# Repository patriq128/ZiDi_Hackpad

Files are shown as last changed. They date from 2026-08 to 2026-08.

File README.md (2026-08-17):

# ZiDi_Hackpad

My Hackpad is a 6-key macropad with an OLED display, rotary encoder, and my own custom firmware.

## Features

* 6 keys in a matrix
* EC11 rotary encoder
* 128x32 OLED display
* Custom firmware

## CAD Model

I am not very experienced with CAD, but I gave it a try.

The case is held together with 4 M3 bolts and heat-set inserts. The PCB is not directly mounted to the case; instead, it is supported by external supports that keep it securely in position.

The case consists of two parts: a bottom and a top. I left a small gap between the parts to make sure they fit together properly.

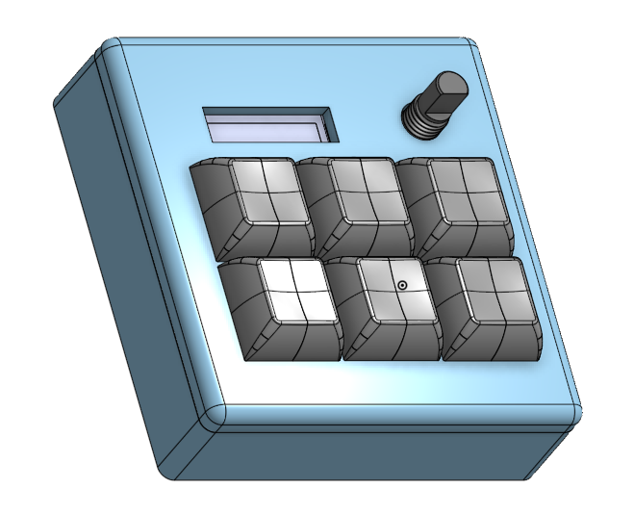
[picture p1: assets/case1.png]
case1


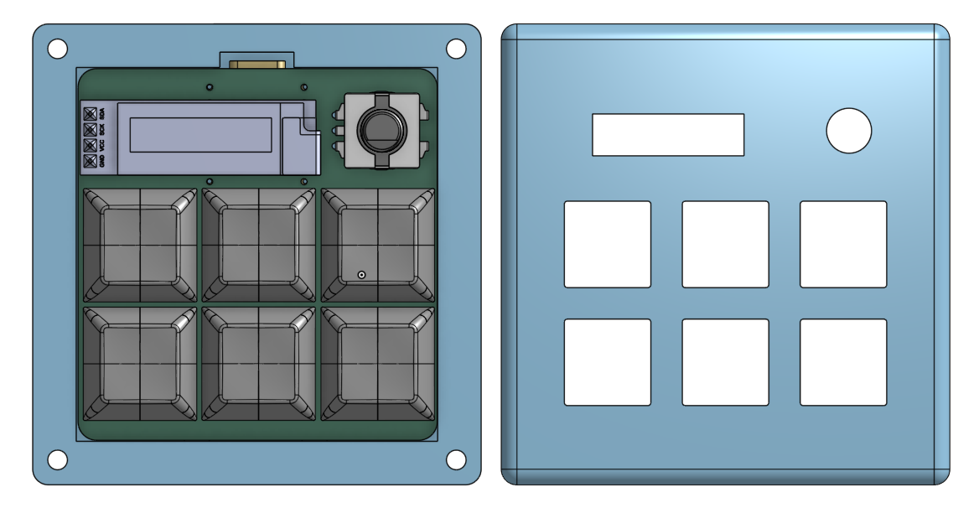
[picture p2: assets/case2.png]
case2


Made in **Onshape**.

## PCB

The PCB was designed in **KiCad**.

### Schematic

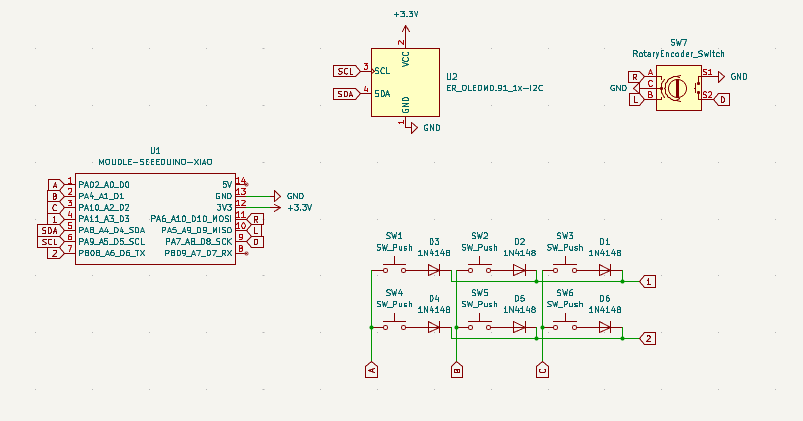
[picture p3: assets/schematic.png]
schematic


The schematic is quite basic, but it works.

### PCB

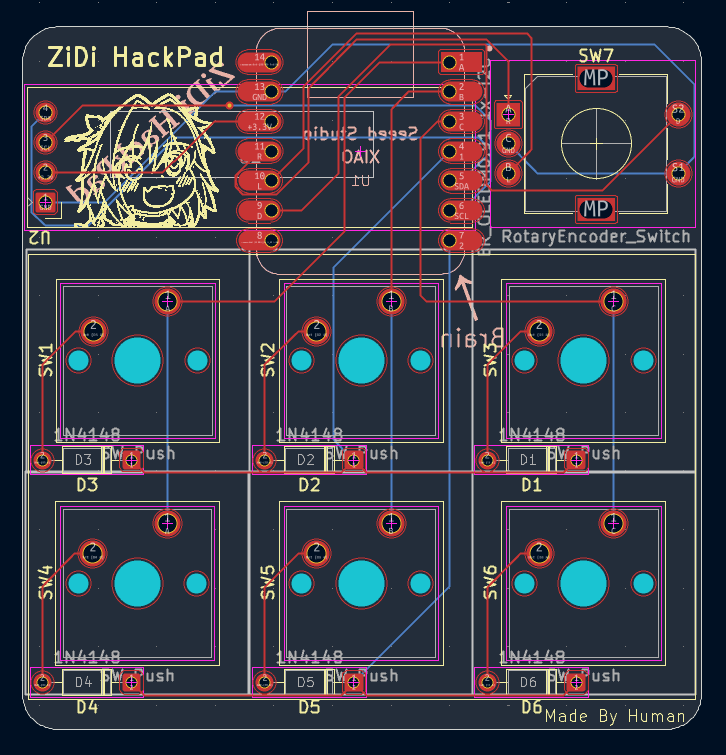
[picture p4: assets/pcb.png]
pcb




## Firmware

I decided to make the firmware a separate project, so you can find it here:



The `Firmware` folder contains everything you need to run the firmware, including a `conf.json` file with some example modes.

The `production` folder contains `firmware.uf2`, which is the CircuitPython firmware compiled and packaged as a UF2 file, ready to be flashed onto the device.

> Want to create something similar yourself? Check out this guide: [Create Custom UF2 File for Easy CircuitPython Flashing](https://embeddedcomputing.com/technology/open-source/create-custom-uf2-file-for-easy-circuitpython-flashing)

## BOM

* 6x Cherry MX switches
* 6x DSA keycaps
* 6x 1N4148 DO-35 diodes
* 1x 0.91" 128x32 OLED display
* 1x EC11 rotary encoder
* 1x XIAO RP2040
* 4x M3x16mm screws
* 4x M3x5mm heat-set inserts
* 1x 3D-printed case

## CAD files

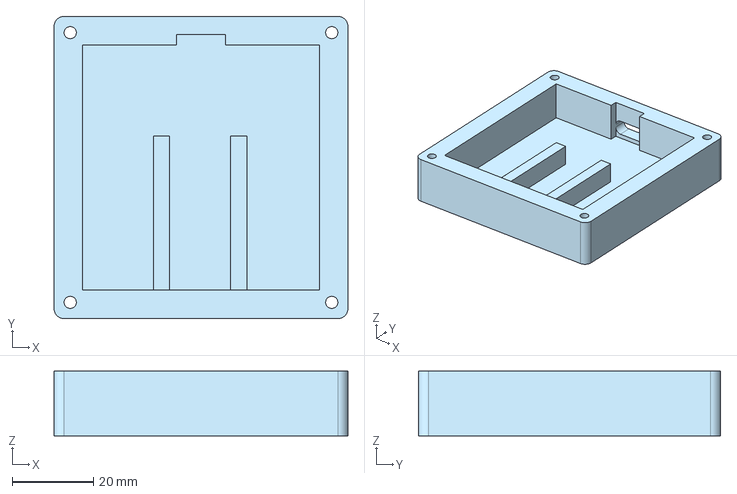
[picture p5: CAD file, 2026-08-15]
CAD/Case - Bottom.step
72.4 x 74.4 x 16.0 mm

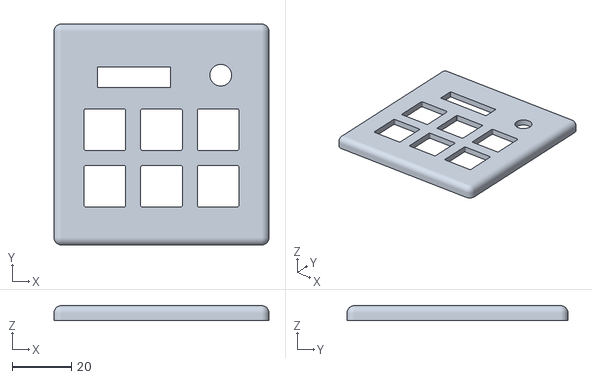
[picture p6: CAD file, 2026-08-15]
Production/top.stl
72.4 x 74.4 x 5.00

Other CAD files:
CAD/Case - Top.step
Production/bottom.stl

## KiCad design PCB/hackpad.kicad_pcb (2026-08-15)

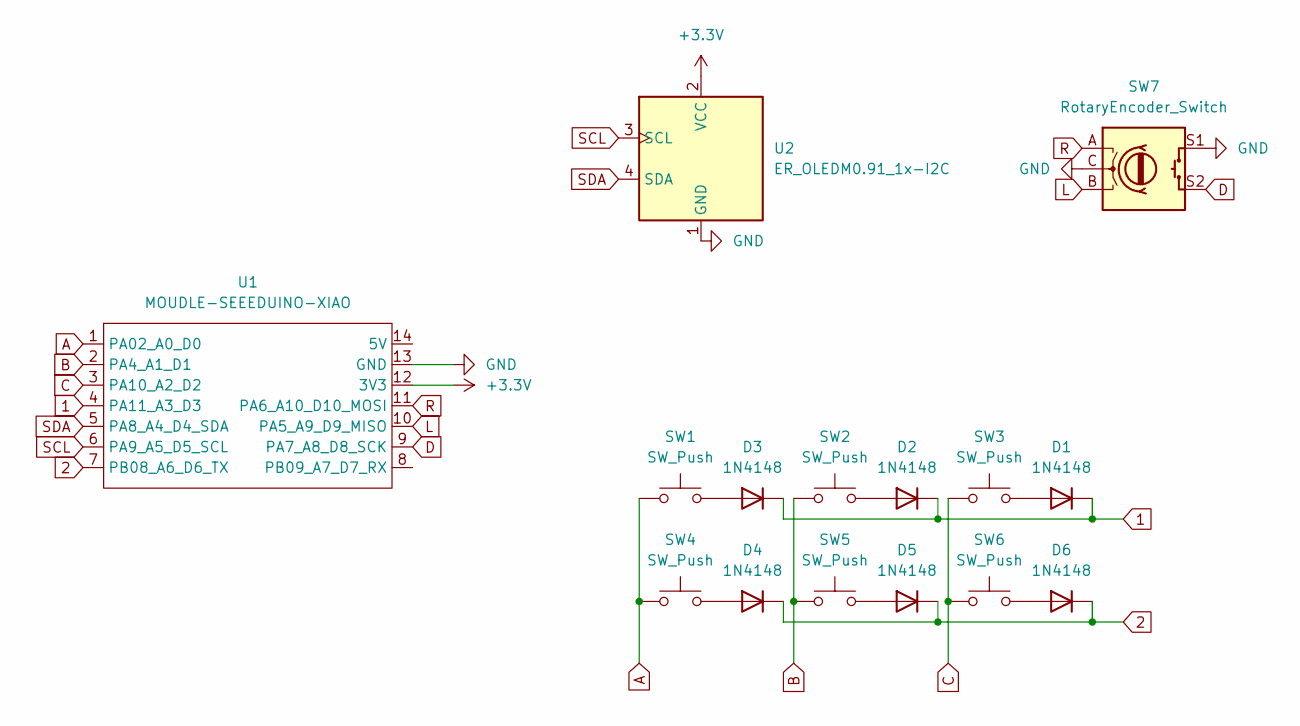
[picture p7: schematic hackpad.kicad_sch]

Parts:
D1, D2, D3, D4, D5, D6: 1N4148; D_DO-35_SOD27_P7.62mm_Horizontal
SW1, SW2, SW3, SW4, SW5, SW6: SW_Push; SW_Cherry_MX_1.00u_PCB
SW7: RotaryEncoder_Switch; RotaryEncoder_Alps_EC11E-Switch_Vertical_H20mm
U1: MOUDLE-SEEEDUINO-XIAO; XIAO-Generic-Hybrid-14P-2.54-21X17.8MM
U2: ER_OLEDM0.91_1x-I2C

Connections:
1: D1.1 (K), D2.1 (K), D3.1 (K), U1.4 (PA11_A3_D3)
2: D4.1 (K), D5.1 (K), D6.1 (K), U1.7 (PB08_A6_D6_TX)
+3.3V: U1.12 (3V3), U2.2 (VCC)
A: SW1.1, SW4.1, U1.1 (PA02_A0_D0)
B: SW2.1, SW5.1, U1.2 (PA4_A1_D1)
C: SW3.1, SW6.1, U1.3 (PA10_A2_D2)
D: SW7.S2, U1.9 (PA7_A8_D8_SCK)
GND: SW7.C, SW7.S1, U1.13 (GND), U2.1 (GND)
L: SW7.B, U1.10 (PA5_A9_D9_MISO)
unnamed: D1.2 (A), SW3.2
unnamed: D2.2 (A), SW2.2
unnamed: D3.2 (A), SW1.2
unnamed: D4.2 (A), SW4.2
unnamed: D5.2 (A), SW5.2
unnamed: D6.2 (A), SW6.2
R: SW7.A, U1.11 (PA6_A10_D10_MOSI)
SCL: U1.6 (PA9_A5_D5_SCL), U2.3 (SCL)
SDA: U1.5 (PA8_A4_D4_SDA), U2.4 (SDA)

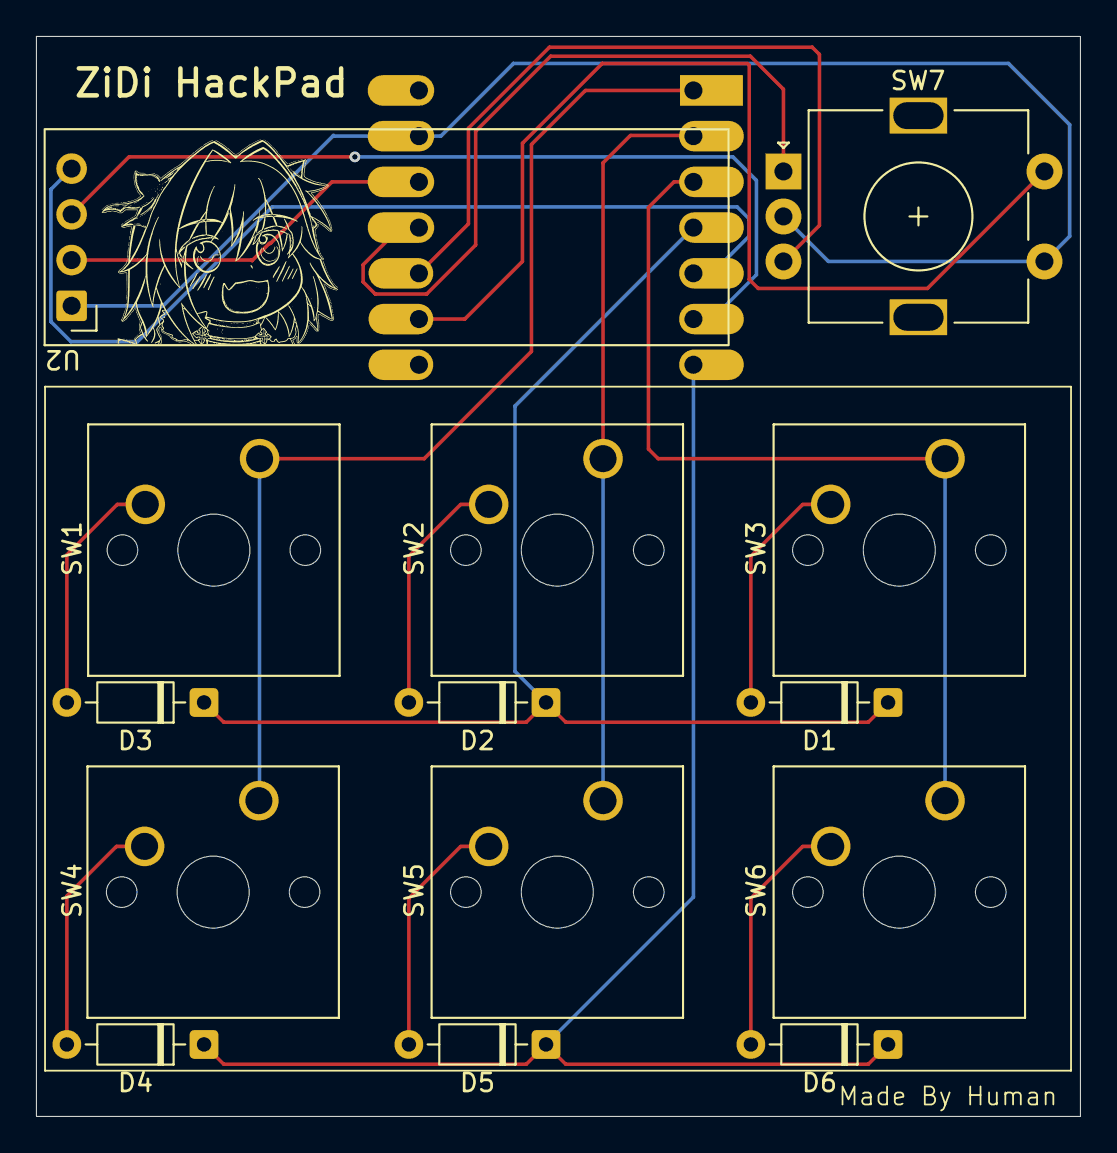
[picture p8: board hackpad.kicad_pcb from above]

Board: 2 copper layers, 58.0 x 60.0 mm, 15 parts (1 on the bottom side), 18 nets.

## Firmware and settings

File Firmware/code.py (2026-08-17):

import board #type: ignore
import keypad #type: ignore
import json #type: ignore
import digitalio #type: ignore
import time
import usb_hid #type: ignore
from adafruit_hid.keyboard import Keyboard #type: ignore
from adafruit_hid.keycode import Keycode #type: ignore

import busio #type: ignore
import displayio #type: ignore
import adafruit_ssd1306 #type: ignore


displayio.release_displays()

i2c = busio.I2C(board.GP5, board.GP4)

display = adafruit_ssd1306.SSD1306_I2C(
    128,
    32,
    i2c,
    addr=0x3C
)

keyboard = Keyboard(usb_hid.devices)

matrix = keypad.KeyMatrix(
    row_pins=(board.GP3, board.GP6),
    column_pins=(board.GP0, board.GP1, board.GP2)
)

mode_button = digitalio.DigitalInOut(board.GP8)
mode_button.direction = digitalio.Direction.INPUT
mode_button.pull = digitalio.Pull.UP

def get():
    global data
    global modes
    with open("/conf.json") as f:
        data = json.load(f)
    modes = list(data["Modes"].keys())

get()
current_mode = 0

def display_mode():
    global current_mode

    display.fill(0)
    text = f"Mode: {modes[current_mode]}"
    x = (128 - len(text) * 6) // 2
    y = (32 - 8) // 2
    display.text(text, x, y, 1)
    display.show()

def switch_mode():
    global current_mode

    current_mode += 1

    if current_mode >= len(modes):
        current_mode = 0
    display_mode()


def send_key(key):
    KEY_ALIASES = {
        "CTRL": Keycode.CONTROL,
        "CONTROL": Keycode.CONTROL,

        "SHIFT": Keycode.SHIFT,

        "ALT": Keycode.ALT,

        "GUI": Keycode.GUI,
        "WINDOWS": Keycode.GUI,
        "WIN": Keycode.GUI,

        "ENTER": Keycode.ENTER,
        "RETURN": Keycode.RETURN,

        "ESC": Keycode.ESCAPE,
        "ESCAPE": Keycode.ESCAPE,

        "TAB": Keycode.TAB,
        "SPACE": Keycode.SPACE,

        "BACKSPACE": Keycode.BACKSPACE,
        "DELETE": Keycode.DELETE,

        "UP": Keycode.UP_ARROW,
        "DOWN": Keycode.DOWN_ARROW,
        "LEFT": Keycode.LEFT_ARROW,
        "RIGHT": Keycode.RIGHT_ARROW,
    }

    def get_keycode(name):
        name = name.upper()

        if name in KEY_ALIASES:
            return KEY_ALIASES[name]

        return getattr(Keycode, name, None)
    
    mode = modes[current_mode]
    info = data["Modes"][mode][str(key)]

    if isinstance(info, list):
        keycodes = []

        for key_name in info:
            keycode = get_keycode(key_name)

            if keycode is not None:
                keycodes.append(keycode)

        if keycodes:
            keyboard.press(*keycodes)
            keyboard.release_all()

    elif isinstance(info, str):
        for char in info:
            keycode = get_keycode(char)

            if keycode is not None:
                if char.isupper():
                    keyboard.press(Keycode.SHIFT)
                    keyboard.press(keycode)
                    keyboard.release(keycode)
                    keyboard.release(Keycode.SHIFT)
                else:
                    keyboard.press(keycode)
                    keyboard.release(keycode)
            else:
                keyboard.press(Keycode.SPACE)
                keyboard.release(Keycode.SPACE)

def recive_serial():
    import usb_cdc  # type: ignore

    if usb_cdc.data is None:
        return

    if usb_cdc.data.in_waiting:
        command = usb_cdc.data.readline().decode().strip()

        if command == "storage":
            with open("/conf.json", "r") as f:
                config = json.load(f)

            config["storage"] = True

            with open("/conf.json", "w") as f:
                json.dump(config, f)

        if command == "send":
            with open("/conf.json", "r") as f:
                data = f.read()

            usb_cdc.data.write(b"FILE_START\n")
            usb_cdc.data.write(data.encode())
            usb_cdc.data.write(b"\nFILE_END\n")

        if command == "get":
            new_config = ""

            while True:
                if usb_cdc.data.in_waiting:
                    line = usb_cdc.data.readline().decode()

                    if line.strip() == "<END>":
                        break

                    new_config += line

            with open("/conf.json", "w") as f:
                f.write(new_config)

            get()

display_mode()


last_button = True

while True:
    recive_serial()
    button = mode_button.value

    if last_button and not button:
        switch_mode()

    last_button = button

    event = matrix.events.get()

    if event and event.pressed:
        send_key(event.key_number)

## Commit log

2026-08-15 update CAD
    [Case - Bottom.step, Case - Top.step]
2026-08-15 Add PCB
    [hackpad.kicad_pcb, hackpad.kicad_sch]
2026-08-15 Added Production
    [bottom.stl, top.stl]
